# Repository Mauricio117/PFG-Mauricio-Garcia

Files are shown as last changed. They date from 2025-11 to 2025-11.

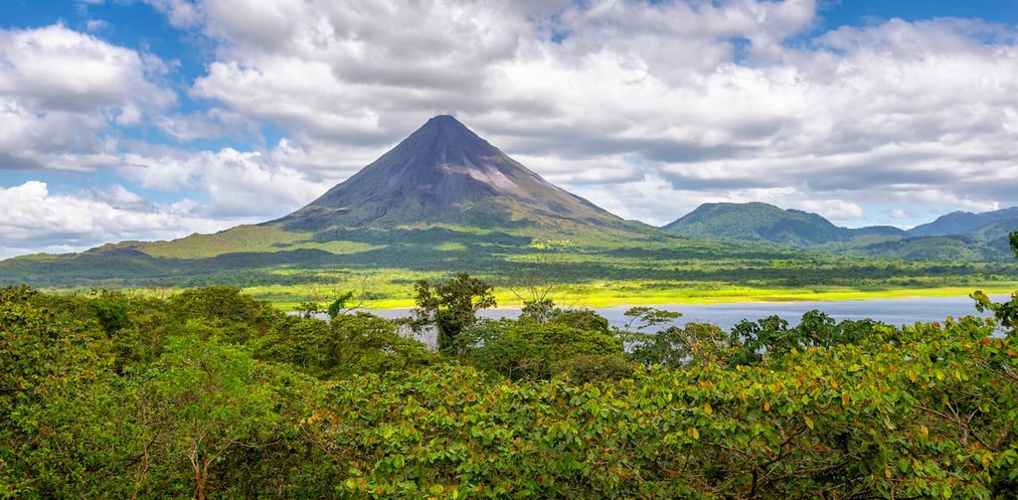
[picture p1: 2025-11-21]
Codigo TFG/imagenes/Costa_Rica.jpg

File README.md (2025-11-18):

# PFG-Mauricio-Garcia
Este repositorio contiene información del Proyecto Final de Graduación realizado en el LIMA del Tecnológico de Costa Rica. Se encuentran los archivos de programa de la interfaz gráfica: programación del Teensy e interfaz gráfica, y los modelos .stl de las piezas utilizadas en la implementación física.

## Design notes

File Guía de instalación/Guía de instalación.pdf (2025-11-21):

## Guía de instalación

## Dispositivo de rehabilitación de rodilla

En primer lugar, acceda al siguiente enlace:

https://www.python.org/downloads/

En la página, seleccione una versión de Python 3.10.x para la descarga.

En el desarrollo de este proyecto se utilizó Python 3.12.6, sin embargo, por

compatibilidad con las bibliotecas gráficas y de comunicación empleadas (Pygame,

Adafruit IO, pyserial y cryptography), se recomienda instalar la versión Python

3.10.14.

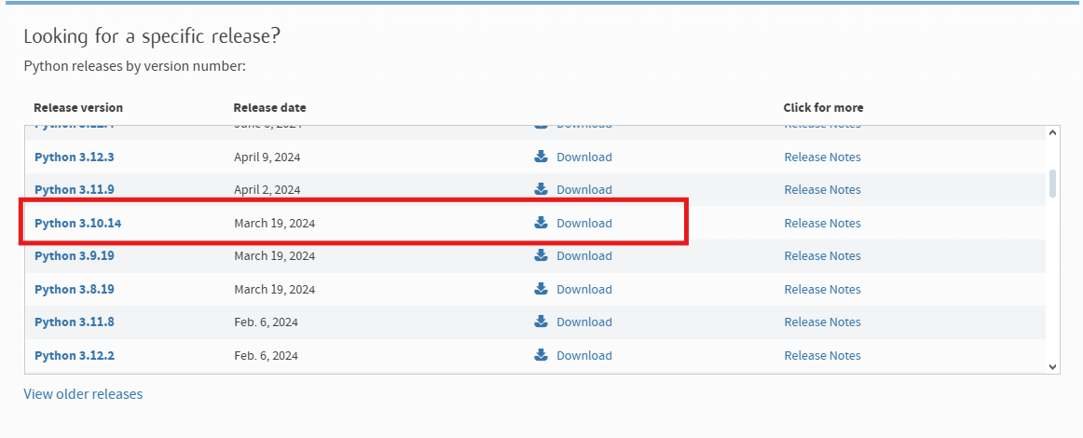
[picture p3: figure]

Una vez descargado, complete la instalación siguiendo los pasos del instalador,

asegurándose de marcar la opción “Add Python to PATH”.

Luego, abra el CMD de Windows y digite los siguientes comandos para instalar las

bibliotecas requeridas:

- pip install requests
- pip install pillow
- pip install adafruit-io
- pip install pygame
- pip install pyserial

Ahora debe instalar Arduino.

Para ello, vaya al enlace:

https://www.arduino.cc/en/software/

En la página, haga clic en la opción "Win 7 and newer". Una vez descargado, instale

el programa. Es importante que la versión de Arduino sea 1.8.X.

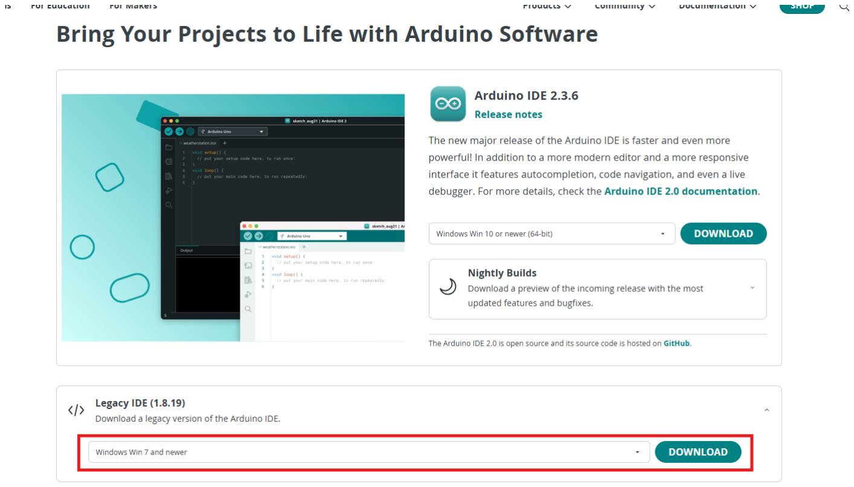
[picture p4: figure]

Luego, debe instalar Teensyduino para poder cargar el programa al Teensy 4.1.

Diríjase a:

https://www.pjrc.com/teensy/td_download.html

Descargue el instalador según el sistema operativo y siga los pasos que se

muestran.

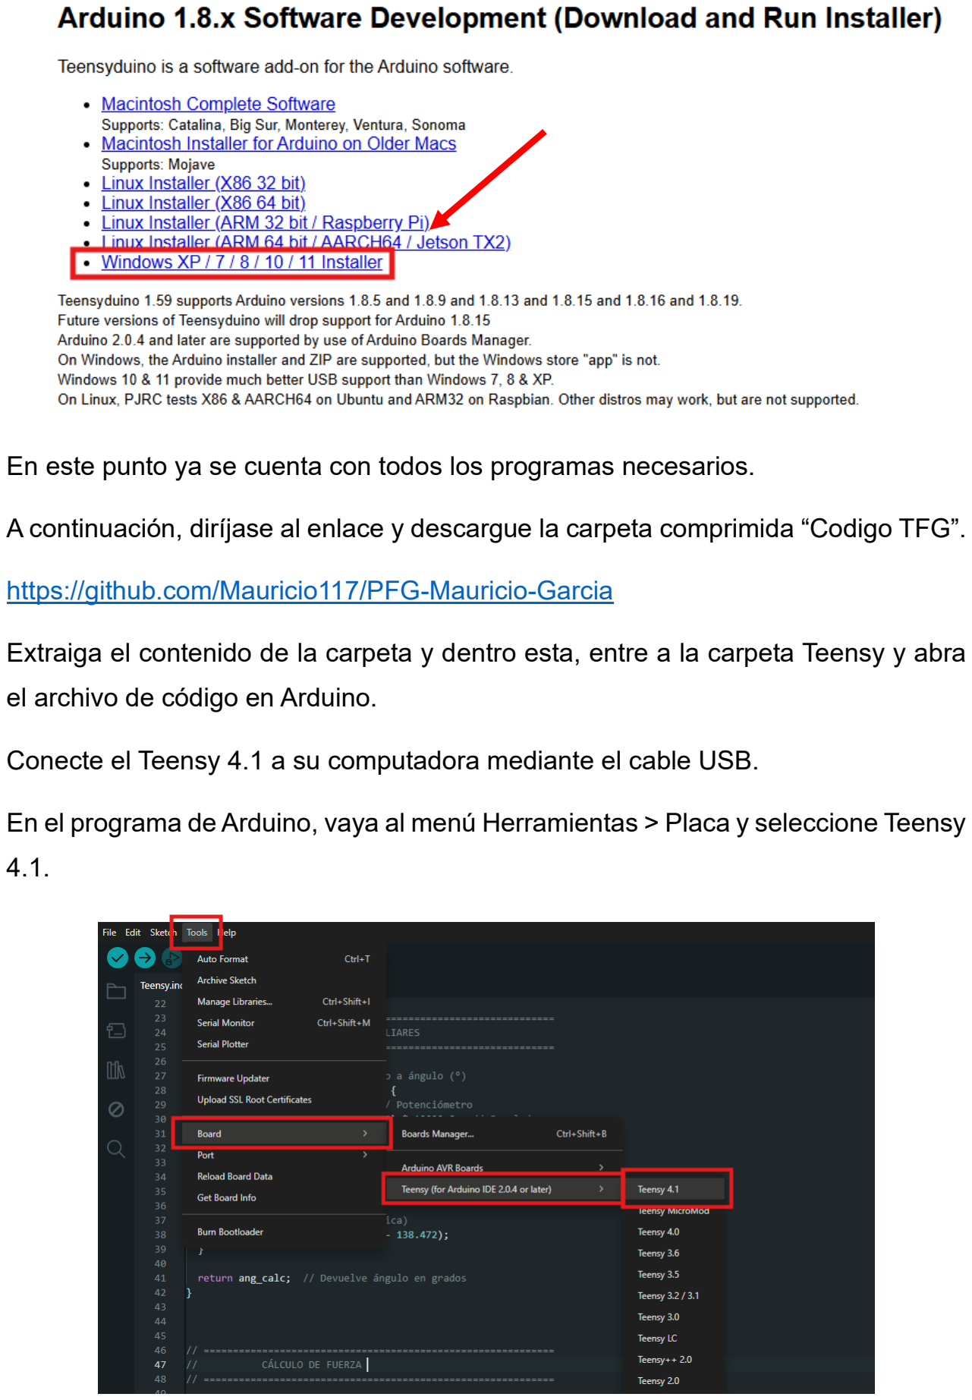
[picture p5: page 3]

En este punto ya se cuenta con todos los programas necesarios.

A continuación, diríjase al enlace y descargue la carpeta comprimida “Codigo TFG”.

https://github.com/Mauricio117/PFG-Mauricio-Garcia

Extraiga el contenido de la carpeta y dentro esta, entre a la carpeta Teensy y abra

el archivo de código en Arduino.

Conecte el Teensy 4.1 a su computadora mediante el cable USB.

En el programa de Arduino, vaya al menú Herramientas > Placa y seleccione Teensy

4.1.

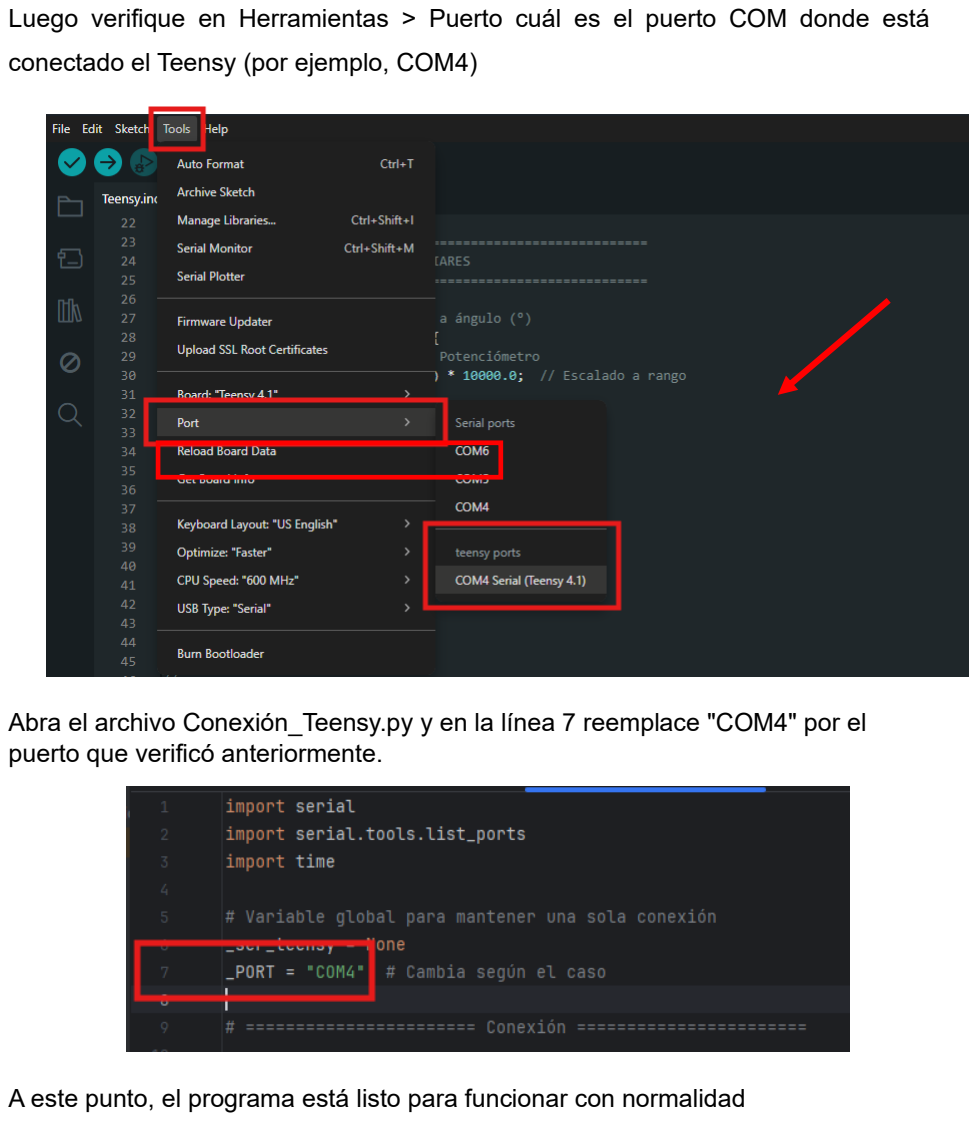
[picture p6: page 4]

Luego verifique en Herramientas > Puerto cuál es el puerto COM donde está

conectado el Teensy (por ejemplo, COM4)

Abra el archivo Conexión_Teensy.py y en la línea 7 reemplace "COM4" por el puerto que verificó anteriormente.

A este punto, el programa está listo para funcionar con normalidad

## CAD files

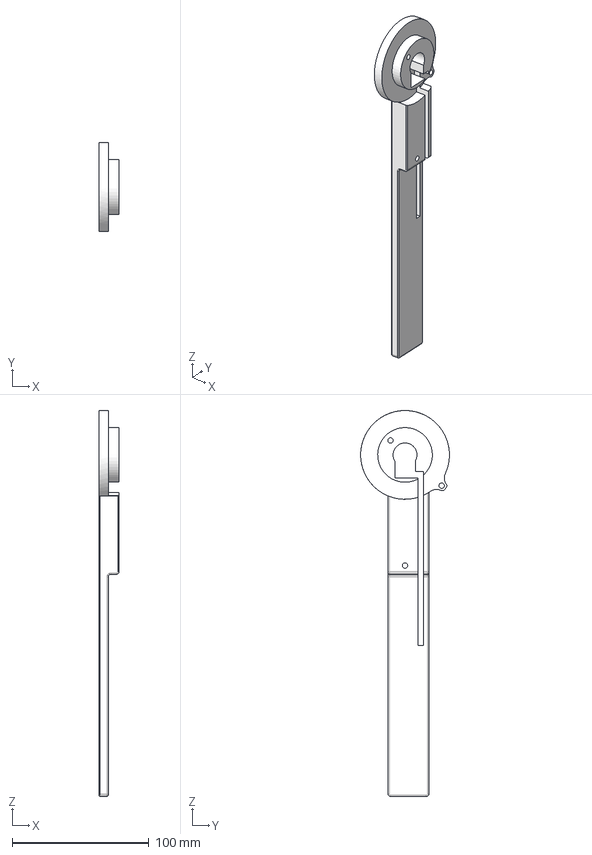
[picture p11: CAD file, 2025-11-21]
CAD/Pieza_horizontal.stp
15.0 x 64.9 x 282.5 mm

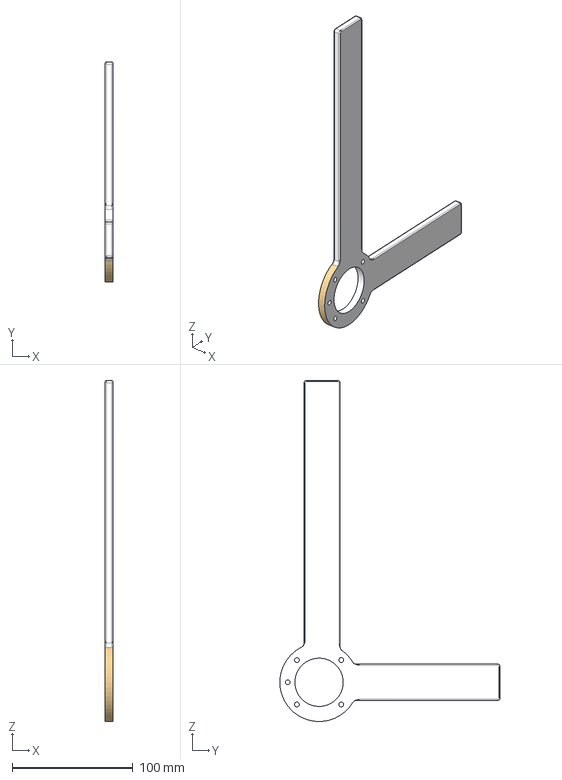
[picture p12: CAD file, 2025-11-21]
CAD/Pieza_vertical.stp
6.42 x 182.5 x 282.5 mm

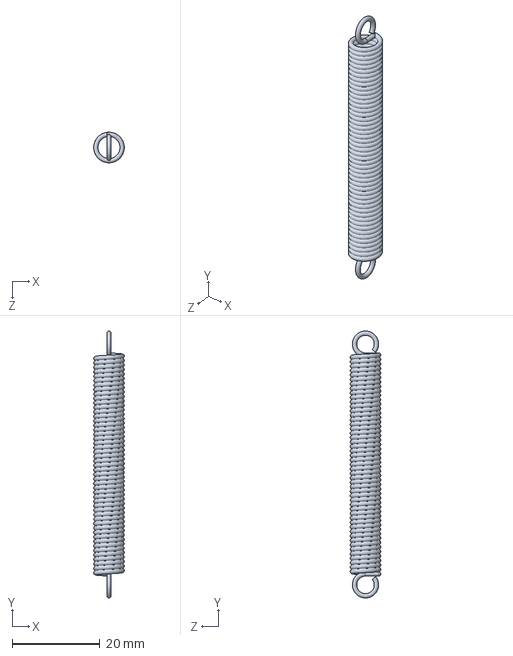
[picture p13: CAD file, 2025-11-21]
CAD/Resorte.SLDPRT
7.00 x 61.0 x 7.00 mm

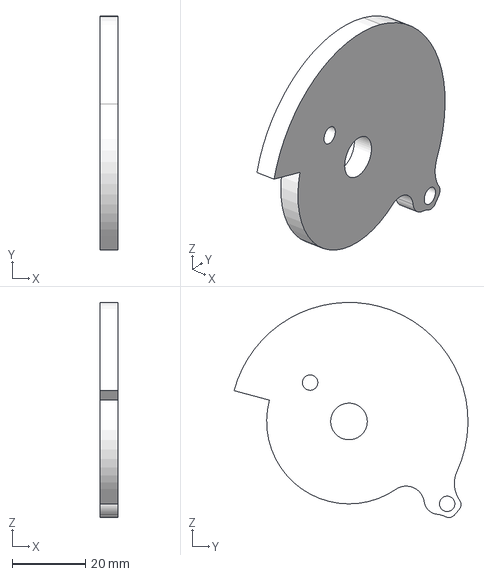
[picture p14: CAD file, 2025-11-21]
CAD/Tapa.stp
5.00 x 63.9 x 58.7 mm

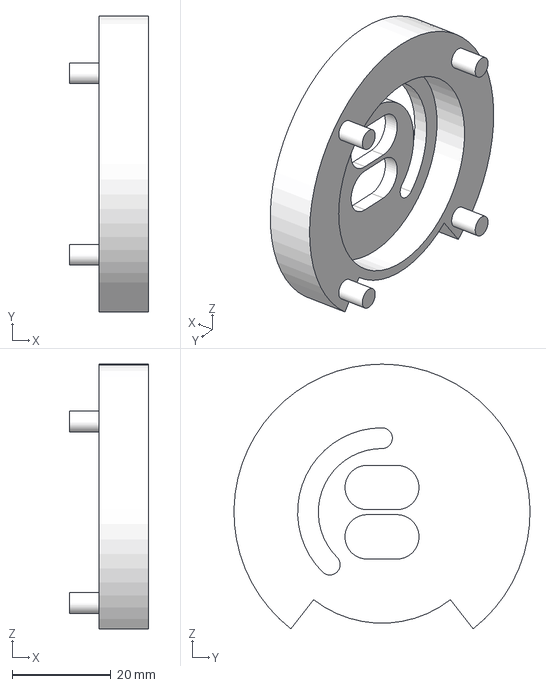
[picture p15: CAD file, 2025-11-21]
CAD/Sujecion potenciometro.stp
16.0 x 60.0 x 53.6 mm

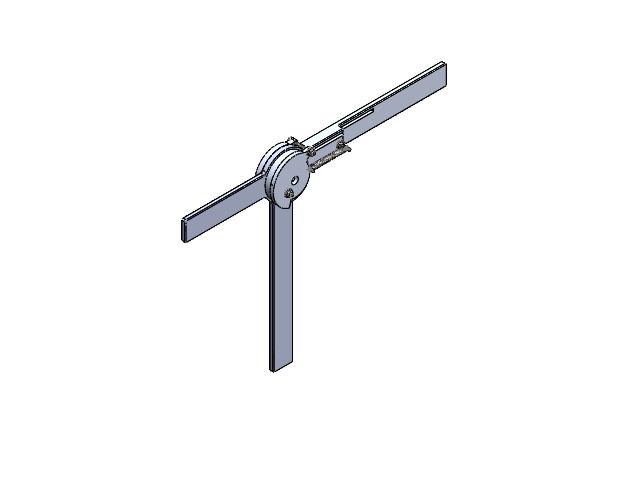
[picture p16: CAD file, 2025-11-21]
CAD/Ensamblaje.SLDASM
pan cross head_am x 4
Pieza_horizontal
Pieza_vertical
Sujecion potenciometro
Tapa
Resorte
flat washer regular_am x 4
hex nut style 1_am x 4

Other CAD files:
CAD/Pieza_horizontal.SLDPRT
CAD/Pieza_vertical.SLDPRT
CAD/Sujecion potenciometro.SLDPRT
CAD/Tapa.SLDPRT

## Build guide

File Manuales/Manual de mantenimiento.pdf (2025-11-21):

## Manual de mantenimiento

## Dispositivo de rehabilitación de rodilla

Mantenimiento preventivo:

El mantenimiento preventivo se realiza periódicamente con el fin de prolongar la

vida útil del dispositivo y reducir la probabilidad de fallos mecánicos, electrónicos o

de software.

Se recomienda efectuarlo cada mes o cada 30 sesiones de uso, lo que ocurra

primero.

Antes de iniciar cualquier procedimiento, asegúrese de:

- Desconectar el cable USB del dispositivo.

Inspección visual general

- Verifique que la estructura fija (zona del muslo) y la estructura móvil (zona

de la pantorrilla) no presenten grietas, deformaciones o desgaste.

- Asegúrese de que el punto de articulación esté firme y sin juego excesivo.
- Revise que la superficie donde el usuario apoya la pierna esté limpia y en

buen estado.

- Compruebe que el cableado que conecta el potenciómetro con el Teensy

4.1 esté intacto y no presente dobleces pronunciados.

Revisión mecánica

- Compruebe que el movimiento manual de la parte móvil sea suave y sin

fricción excesiva.

- Confirme que no existan piezas ni tornillos sueltos.

- Si se escucha sonido metálico o fricción, revise que la articulación esté

correctamente alineada.

Acceso a la parte electrónica

Retire los tornillos de la tapa que cubre la zona de conexión entre piezas

mecánicas.

Abra la tapa interna con cuidado, la cual está conectada con el potenciómetro.

Una vez abierta:

- Verifique el estado del cable USB y las conexiones internas.
- Compruebe que el Teensy 4.1 esté correctamente asentado en su base.
- Revise el cableado del potenciómetro, asegurándose de que los cables

estén bien sujetos y sin desgaste.

- Confirme que no existan signos de calentamiento o corrosión en los

conectores.

Limpieza interna

- Elimine el polvo con aire comprimido o un pincel suave.
- No aplique líquidos ni aerosoles dentro del compartimiento electrónico.

Vuelva a cerrar la tapa y coloque los tornillos.

Limpieza externa

- Limpie las superficies del dispositivo con un paño seco o ligeramente

húmedo.

- Evite productos abrasivos o solventes.
- Asegúrese de que la superficie de apoyo de la pierna esté limpia y libre de

partículas.

Verificación final

- Conecte nuevamente el dispositivo y abra la interfaz.
- Verifique que las lecturas del ángulo sean estables y coherentes.
- Mueva manualmente la estructura móvil y compruebe que el valor mostrado

en pantalla aumente y disminuya correctamente.

- Revise que el puerto COM sea detectado sin errores.
- Compruebe que el juego interactivo responda adecuadamente al

movimiento manual.

Mantenimiento correctivo:

Si el dispositivo presenta fallas durante su uso, utilice la tabla siguiente para

diagnosticar y resolver el problema.

Tabla 1. Fallos comunes y acciones recomendadas

Síntoma o falla detectada | Posible causa | Acción recomendada
El dispositivo no es detectado por la computadora | • Cable USB dañado • Puerto COM inhabilitado | • Cambiar cable USB • Probar otro puerto
La interfaz no muestra lecturas de ángulo | • Potenciómetro desconectado • Cable roto o flojo • Teensy no reconocido | • Revisar conexión del potenciómetro • Verificar continuidad de cables • Reconectar el Teensy
La lectura del ángulo es inestable | • Potenciómetro desgastado • Ruido eléctrico en el cable | • Ajustar conexión • Reemplazar potenciómetro si aplica
El juego no responde al movimiento | • Lectura del potenciómetro errónea • Puerto COM incorrecto | • Revisar cableado • Seleccionar el puerto COM correcto
La interfaz gráfica no inicia | • Librerías no instaladas • Error en el código Python | • Reinstalar librerías requeridas

| | • Revisar mensajes en consola
Datos de usuario no se guardan | • Error de escritura del archivo cifrado • Adafruit IO sin conexión | • Verificar carpeta “Datos Locales” • Revisar conexión a Internet
Ruido en la articulación | • Piezas mal alineadas | • Realinear las piezas
El movimiento manual está rígido | • Acumulación de polvo • Fricción en el punto de giro | • Limpiar superficie de contacto • Revisar y reajustar articulación

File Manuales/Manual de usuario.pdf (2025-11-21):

## Manual de usuario

## Dispositivo de rehabilitación de rodilla

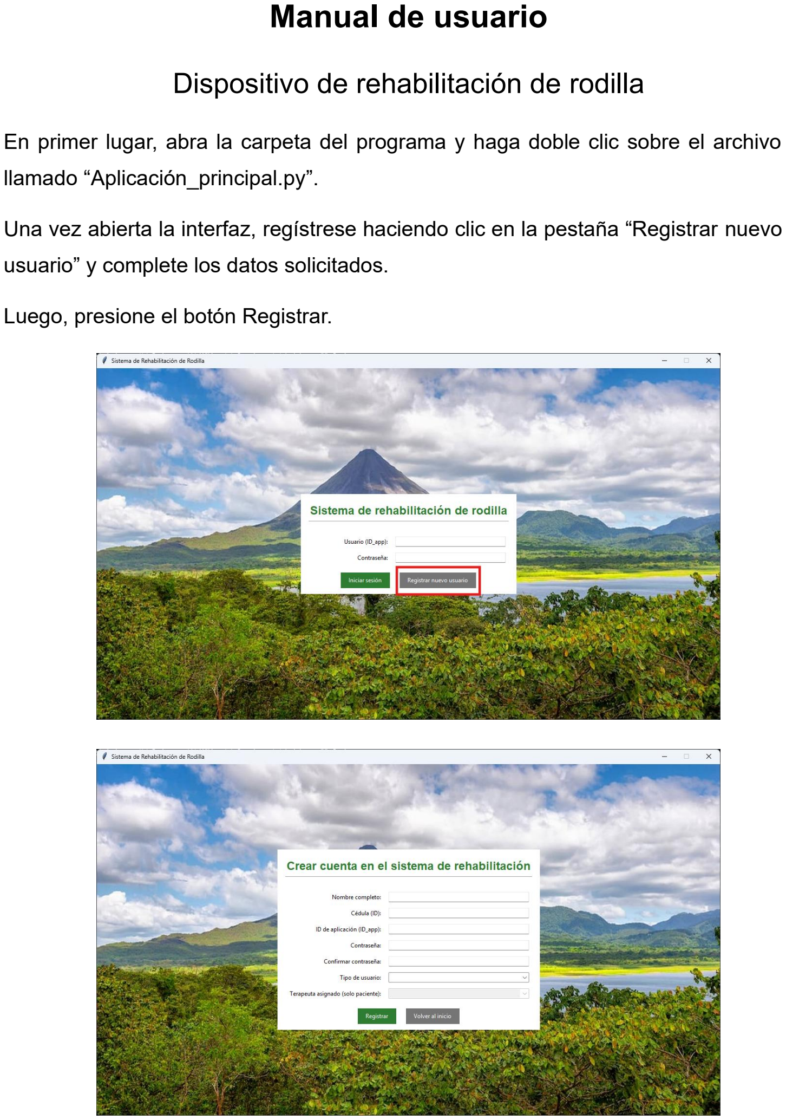
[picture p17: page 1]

En primer lugar, abra la carpeta del programa y haga doble clic sobre el archivo

llamado “Aplicación_principal.py”.

Una vez abierta la interfaz, regístrese haciendo clic en la pestaña “Registrar nuevo

usuario” y complete los datos solicitados.

Luego, presione el botón Registrar.

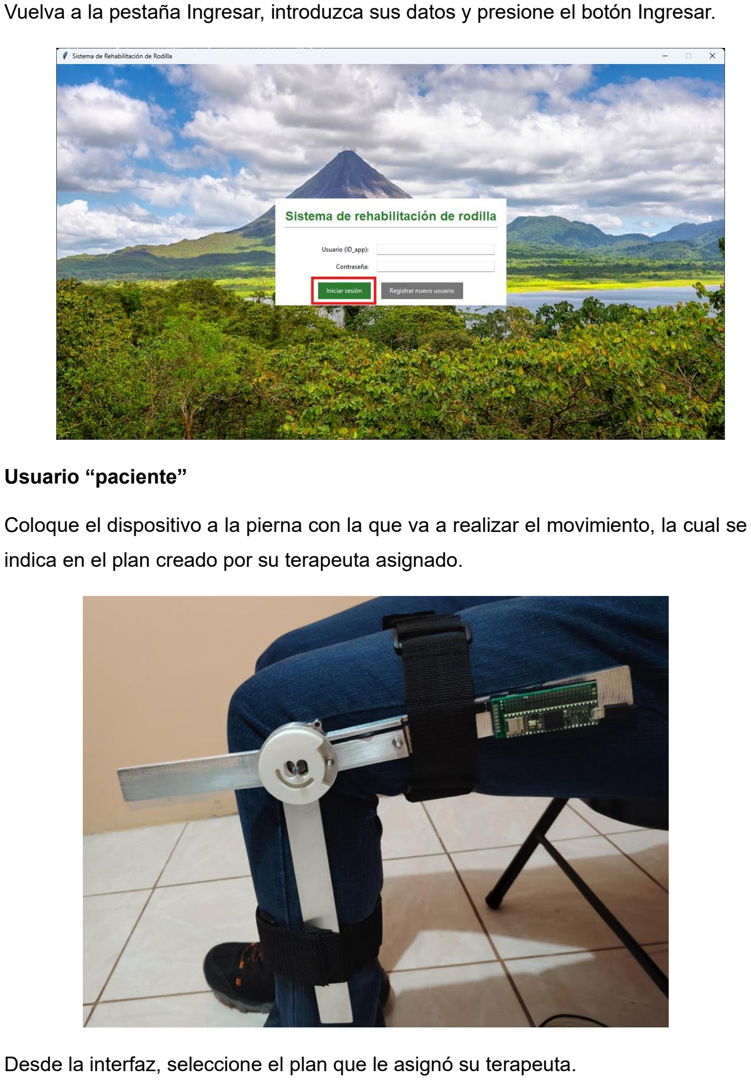
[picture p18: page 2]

Vuelva a la pestaña Ingresar, introduzca sus datos y presione el botón Ingresar.

Usuario “paciente”

Coloque el dispositivo a la pierna con la que va a realizar el movimiento, la cual se

indica en el plan creado por su terapeuta asignado.

Desde la interfaz, seleccione el plan que le asignó su terapeuta.

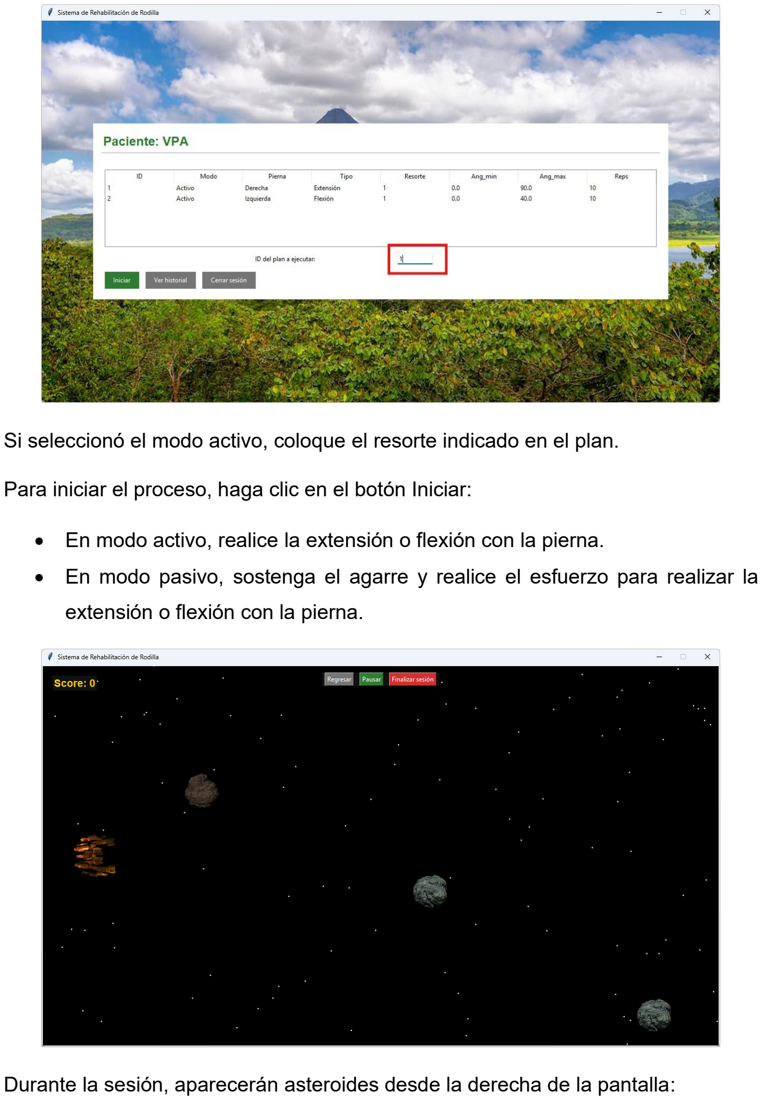
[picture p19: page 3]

Si seleccionó el modo activo, coloque el resorte indicado en el plan.

Para iniciar el proceso, haga clic en el botón Iniciar:

- En modo activo, realice la extensión o flexión con la pierna.
- En modo pasivo, sostenga el agarre y realice el esfuerzo para realizar la

extensión o flexión con la pierna.

Durante la sesión, aparecerán asteroides desde la derecha de la pantalla:

Debe intentar destruirlos moviendo la pierna.

- Si se mueve la pierna hacia arriba, la nave se desplaza hacia arriba.
- Si se mueve la pierna hacia abajo, la nave se desplaza hacia abajo.

La sesión termina al completar las repeticiones indicadas en el plan.

Usuario “terapeuta”

Si inicia sesión con un usuario de tipo “terapeuta”, aparecerá una pantalla con los

datos de las sesiones de los usuarios.

Seleccione un usuario desde la pestaña de paciente. Los panes del paciente se

mostrarán automáticamente. Además, puede crear nuevos planes para dicho

usuario. El botón “Subir a Adafruit IO” permite sincronizar los datos del paciente con

la nube cuando se presenta una conexión activa a internet.

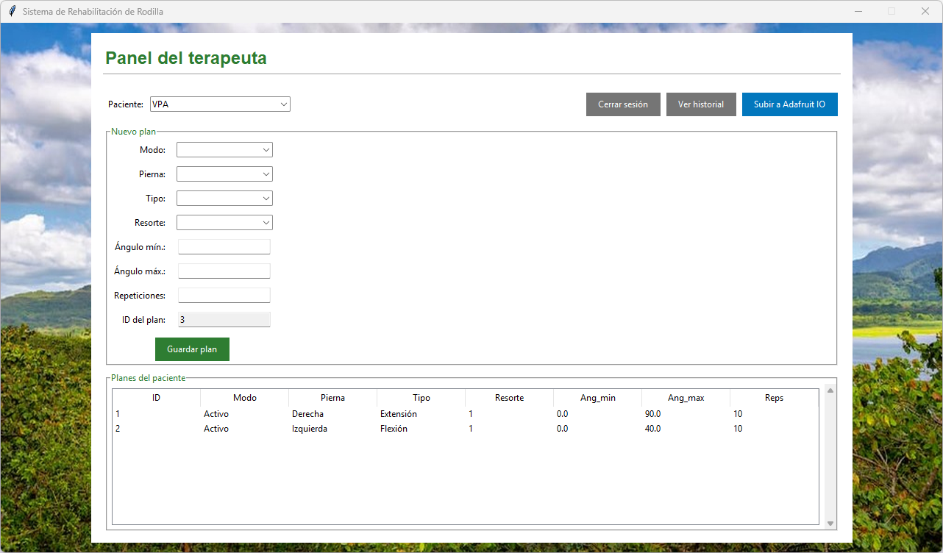
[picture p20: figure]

Para ver el resumen de las sesiones del usuario presione el botón “Ver historial”.

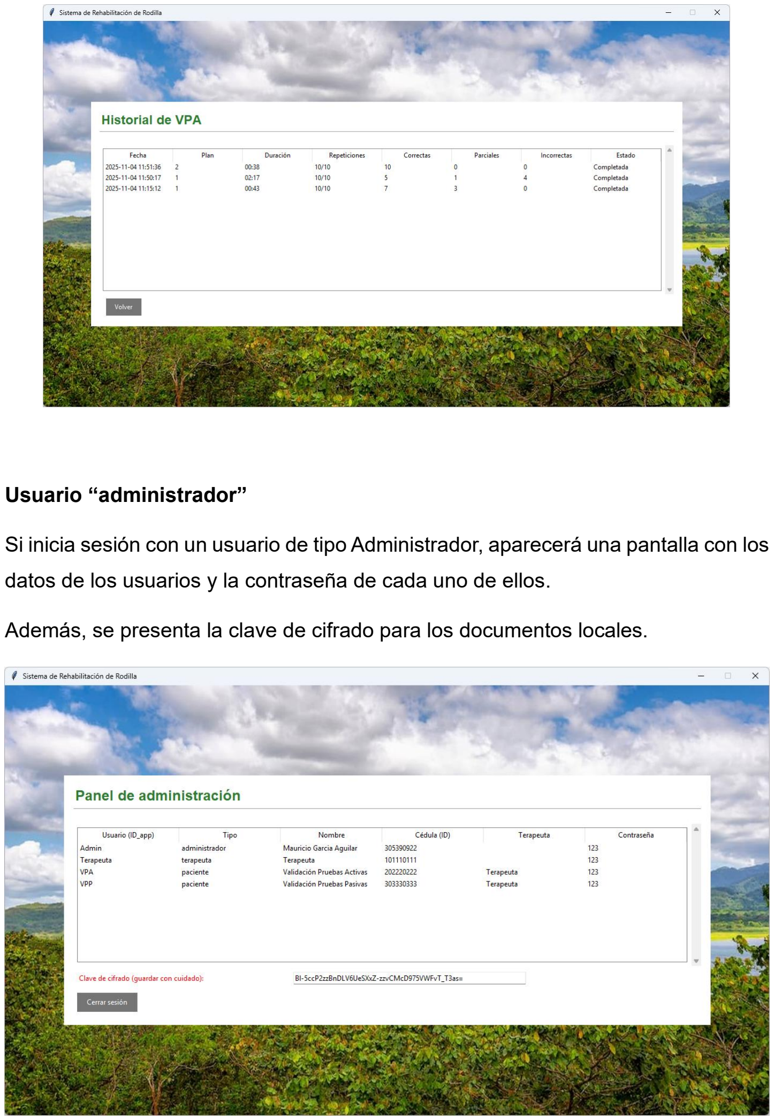
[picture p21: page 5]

Usuario “administrador”

Si inicia sesión con un usuario de tipo Administrador, aparecerá una pantalla con los

datos de los usuarios y la contraseña de cada uno de ellos.

Además, se presenta la clave de cifrado para los documentos locales.

Recomendaciones generales

- No utilice el dispositivo si observa ruidos anormales, lecturas inestables,

holguras en tornillos o desgaste en las piezas.

- Manténgalo en un lugar seco, limpio y protegido, evitando exposición a

humedad, polvo excesivo o temperaturas extremas.

- Utilice el equipo únicamente sobre una superficie firme, estable y nivelada

para asegurar un movimiento adecuado de la articulación.

- Evite manipular cables, piezas internas, el Teensy 4.1 o el software del

sistema sin conocimientos técnicos o sin seguir el manual correspondiente.

- Realice copias de respaldo de los datos almacenados en la aplicación,

especialmente si varios usuarios o terapeutas utilizan el sistema.

- No coloque las manos sobre el mecanismo de movimiento o el eje mientras

el dispositivo se encuentre en funcionamiento.

- Asegúrese de que las sujeciones de la pierna esten correctamente ajustada

antes de iniciar el modo activo o pasivo para evitar deslizamientos.

- Verifique antes de cada sesión que el cable USB y el Teensy estén

correctamente conectados al puerto COM correspondiente.

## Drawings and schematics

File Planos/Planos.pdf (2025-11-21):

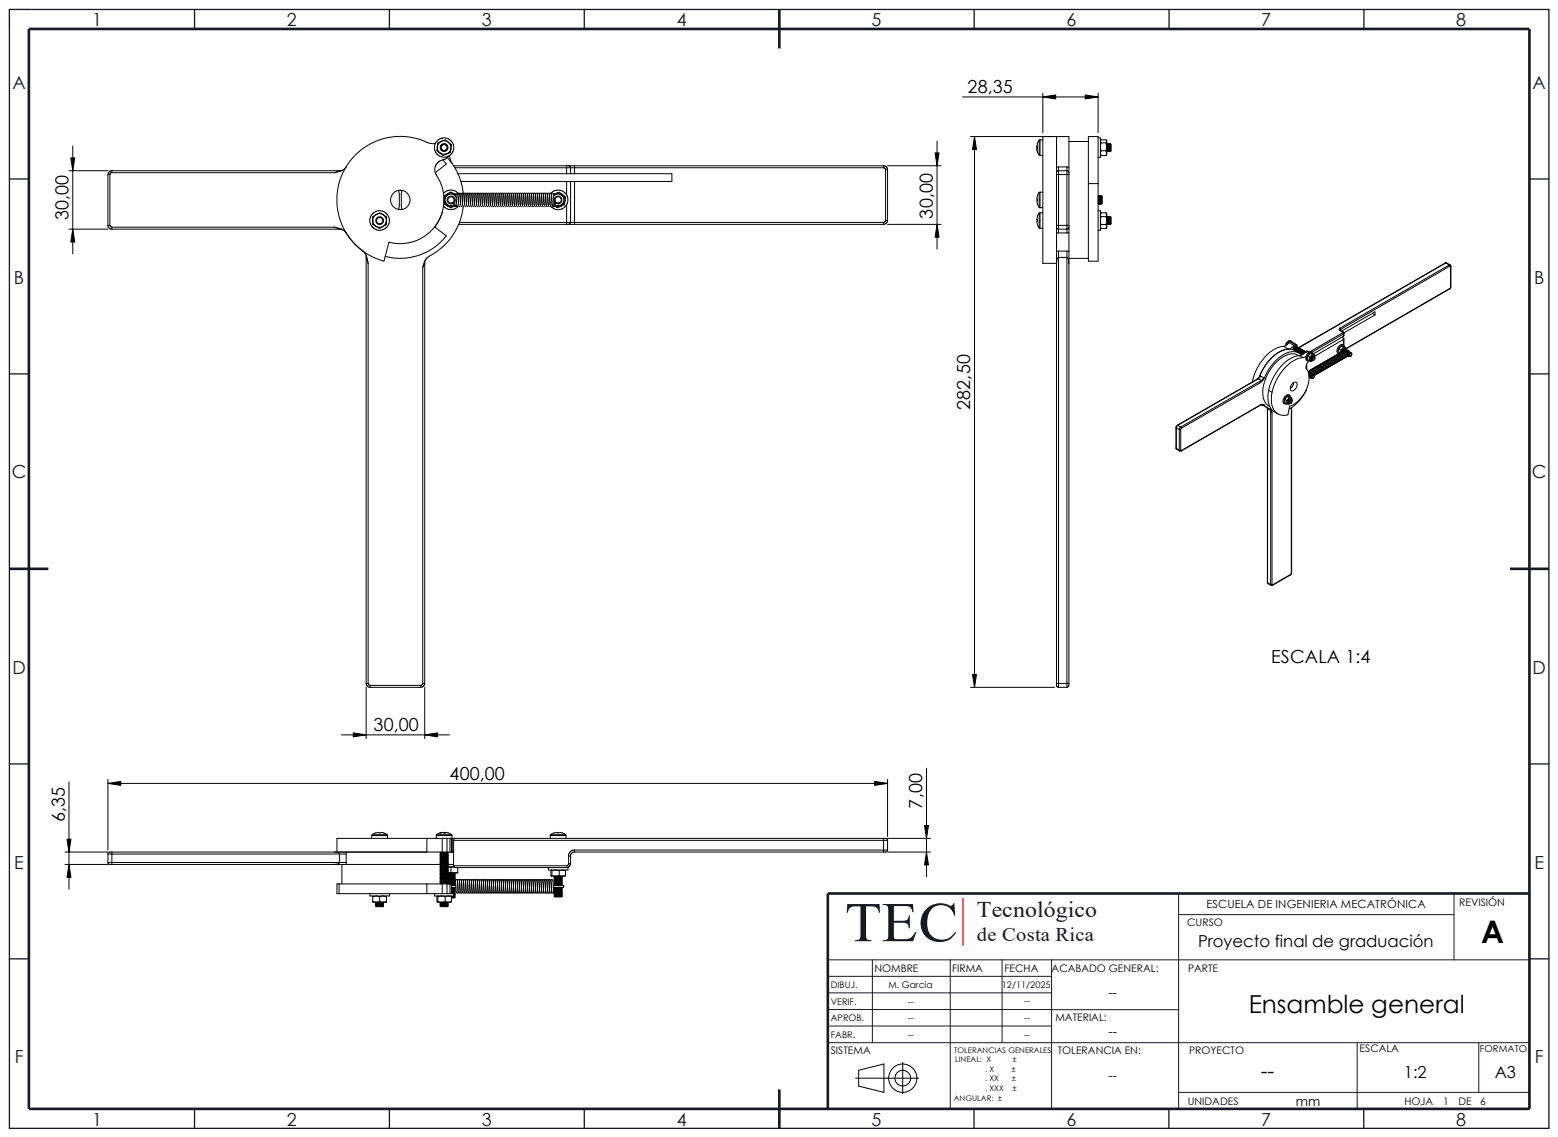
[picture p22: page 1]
Tecnológico TEC; CURSO; REVISIÓN; ESCALA 1:4

ESCUELA DE INGENIERIA MECATRÓNICA
Proyecto final de graduación

de Costa Rica

NOMBRE | FIRMA | FECHA | ACABADO GENERAL: -- | PARTE Ensamble general
DIBUJ. | M. García | | 12/11/2025
VERIF. | -- | | --

APROB. | -- | | -- | MATERIAL: --
FABR. | -- | | --
SISTEMA | | | TOLERANCIAS GENERALES LINEAL: X ± . XX ± . X ± . XXX ± ANGULAR: ± | TOLERANCIA EN: -- | PROYECTO -- | ESCALA 1:2 | FORMATO A3

mm UNIDADES | HOJA 1 6 DE

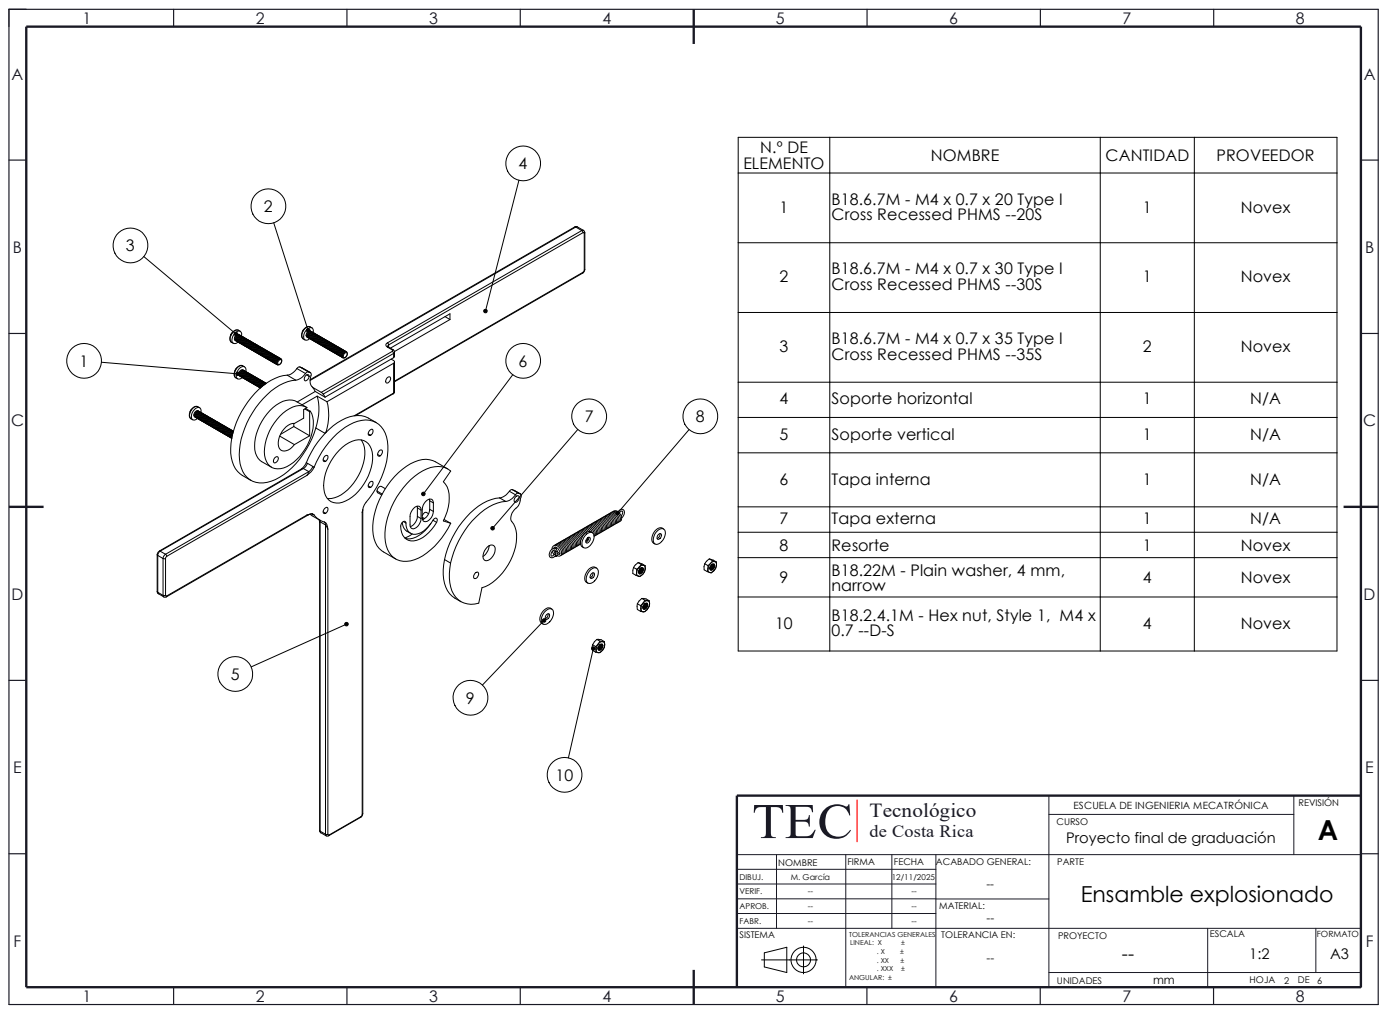
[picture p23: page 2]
Tecnológico TEC; CURSO; REVISIÓN

N.º DE ELEMENTO | NOMBRE | CANTIDAD | PROVEEDOR

1 | B18.6.7M - M4 x 0.7 x 20 Type I Cross Recessed PHMS --20S | 1 | Novex

2 | B18.6.7M - M4 x 0.7 x 30 Type I Cross Recessed PHMS --30S | 1 | Novex

3 | B18.6.7M - M4 x 0.7 x 35 Type I Cross Recessed PHMS --35S | 2 | Novex

4 | Soporte horizontal | 1 | N/A
5 | Soporte vertical | 1 | N/A

6 | Tapa interna | 1 | N/A

7 | Tapa externa | 1 | N/A
8 | Resorte | 1 | Novex
9 | B18.22M - Plain washer, 4 mm, narrow | 4 | Novex

10 B18.2.4.1M - Hex nut, Style 1, M4 x | 0.7 --D-S | 4 | Novex

ESCUELA DE INGENIERIA MECATRÓNICA
Proyecto final de graduación

de Costa Rica

NOMBRE | FIRMA | FECHA | ACABADO GENERAL: -- | PARTE Ensamble explosionado

DIBUJ. | M. García | | 12/11/2025
VERIF. | -- | | --
APROB. | -- | | -- | MATERIAL:
FABR. | | | -- | -- --

LINEAL: X ± . XX ± . X ± . XXX ± ANGULAR: ± | | PROYECTO -- | ESCALA 1:2 | FORMATO

15,00 32,50

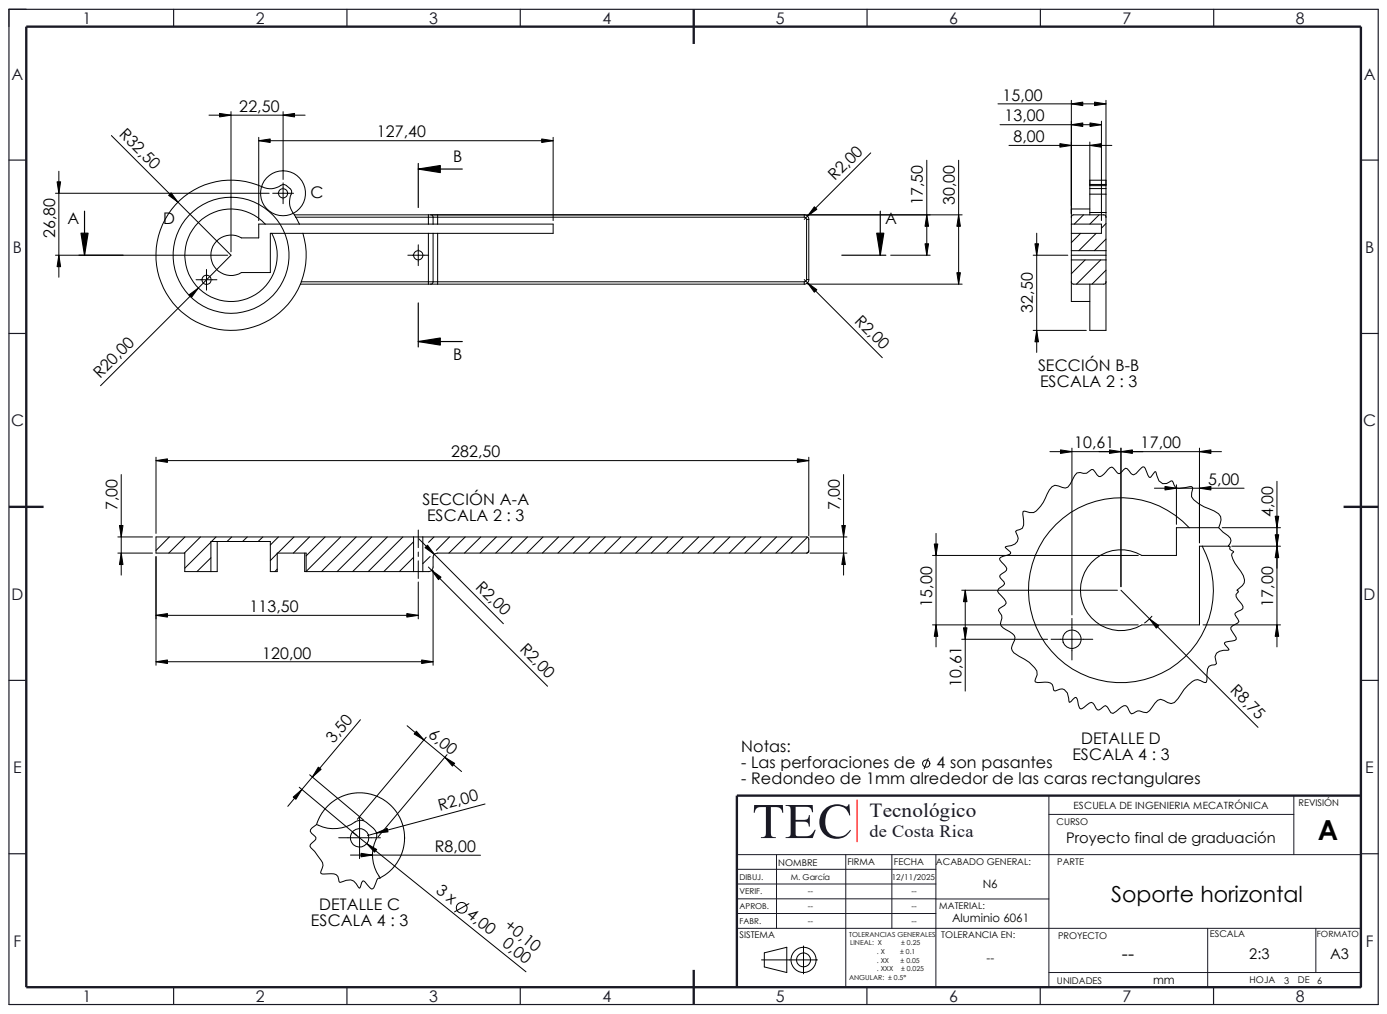
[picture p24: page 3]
SECCIÓN B-B ESCALA 2 : 3; SECCIÓN A-A; ESCALA 2 : 3 ⁷,00; DETALLE C ESCALA 4 : 3; DETALLE D ESCALA 4 : 3; CURSO; REVISIÓN

Notas:
- Las perforaciones de 4 son pasantes
- Redondeo de 1mm alrededor de las caras rectangulares
Tecnológico TEC

ESCUELA DE INGENIERIA MECATRÓNICA
Proyecto final de graduación

de Costa Rica

NOMBRE | FIRMA | FECHA | ACABADO GENERAL: N6 | PARTE Soporte horizontal

DIBUJ. | M. García | | 12/11/2025
VERIF. | -- | | --
APROB. | -- | | -- | MATERIAL: Aluminio 6061
FABR. | -- | | --

LINEAL: X ± 0.25 . XX ± 0.05 . X ± 0.1 . XXX ± 0.025 ANGULAR: ± 0.5° | | PROYECTO -- | ESCALA 2:3 | FORMATO

6,35 8,00

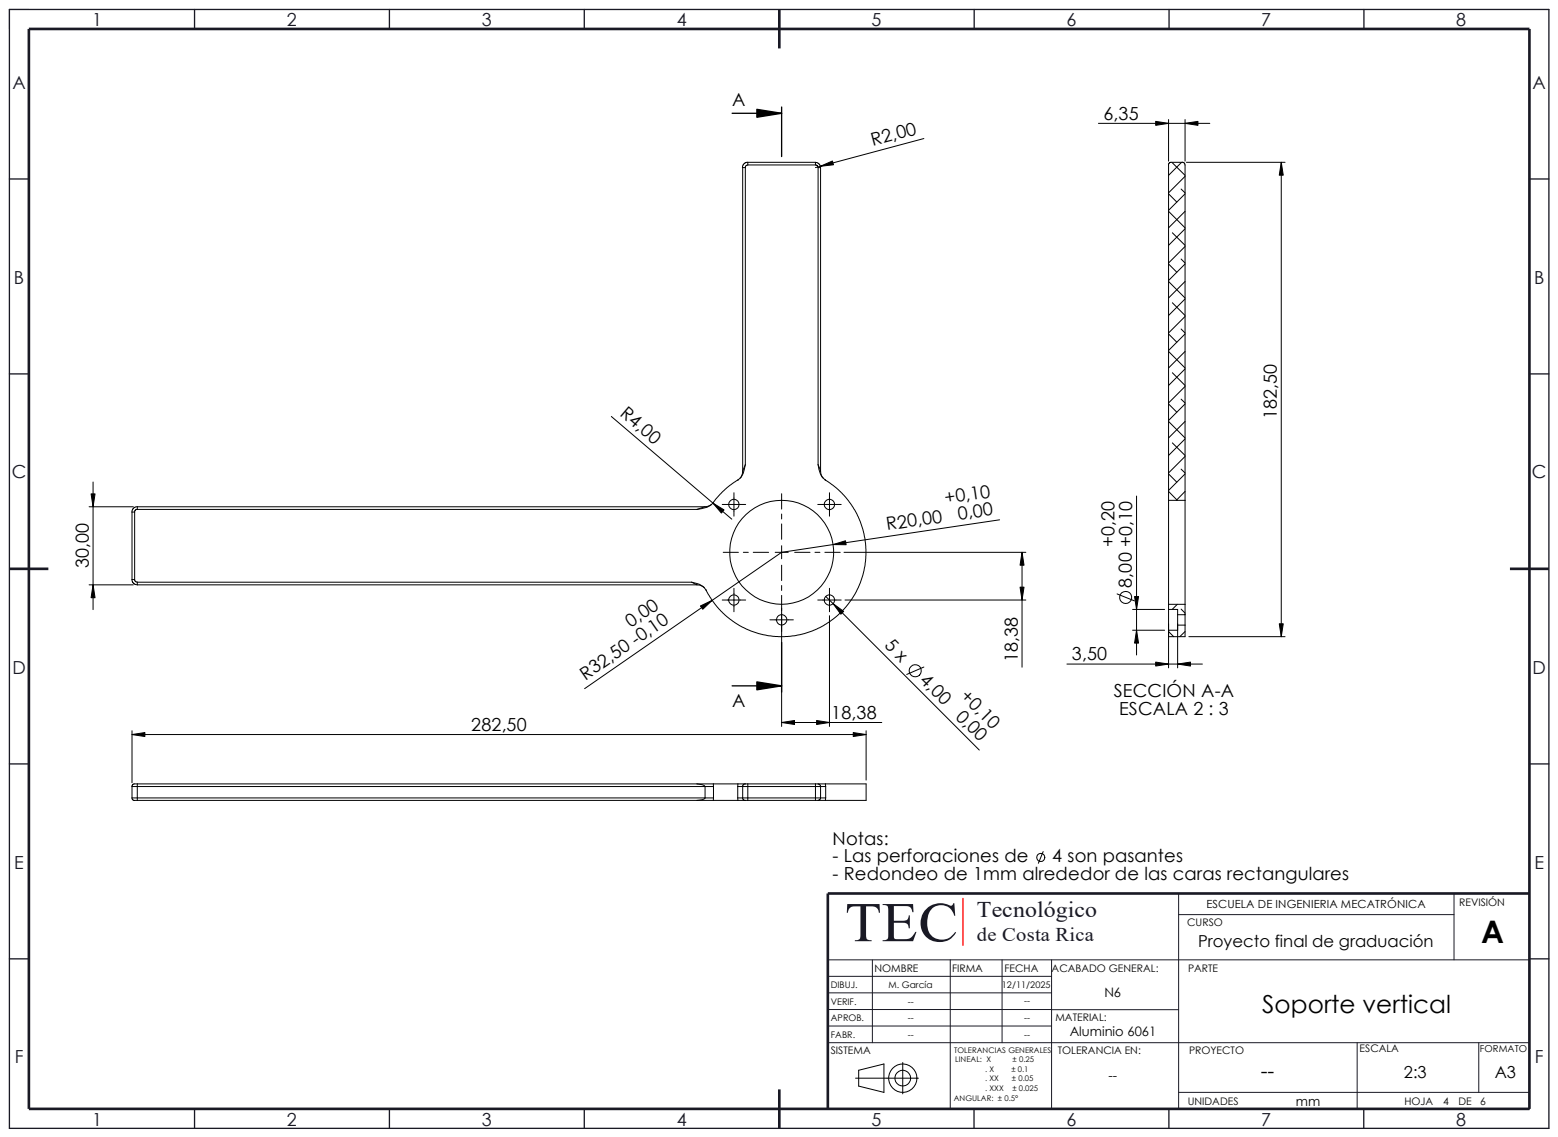
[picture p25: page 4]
SECCIÓN A-A ESCALA 2 : 3; CURSO; REVISIÓN

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

ESCUELA DE INGENIERIA MECATRÓNICA
Proyecto final de graduación

de Costa Rica

NOMBRE | FIRMA | FECHA | ACABADO GENERAL: N6 | PARTE Soporte vertical

DIBUJ. | M. García | | 12/11/2025
VERIF. | -- | | --
APROB. | -- | | -- | MATERIAL: Aluminio 6061
FABR. | -- | | --

. XX ± 0.05 | | PROYECTO -- | ESCALA 2:3 | FORMATO

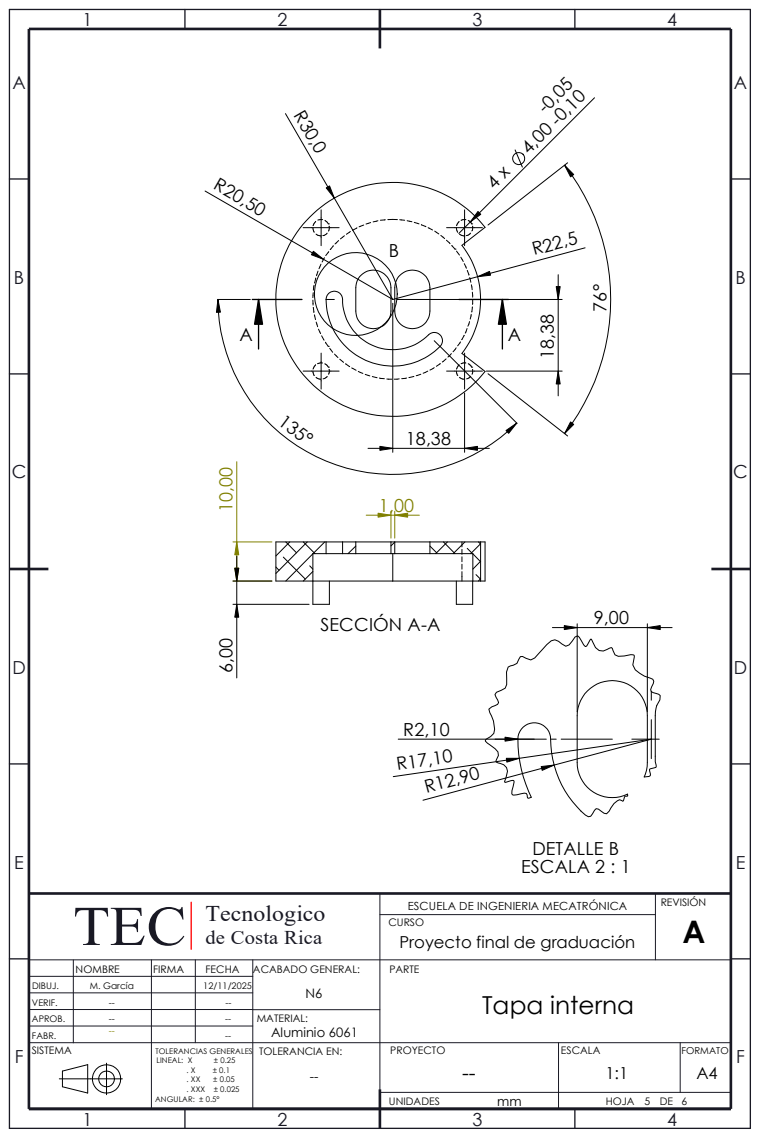
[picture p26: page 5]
SECCIÓN A-A ¹⁰,00; DETALLE B ESCALA 2 : 1; TEC; de Costa Rica; Tecnologico; CURSO; REVISIÓN

ESCUELA DE INGENIERIA MECATRÓNICA
Proyecto final de graduación

NOMBRE | FIRMA | FECHA | ACABADO GENERAL: | PARTE Tapa interna N6

DIBUJ. | M. García | | 12/11/2025
VERIF. | -- | | --
APROB. | -- | | -- | MATERIAL: Aluminio 6061
FABR. | -- | | --

TOLERANCIAS GENERALES . XX ± 0.05 | -- | PROYECTO | ESCALA 1:1 | FORMATO A4

UNIDADES mm | HOJA DE 5 6

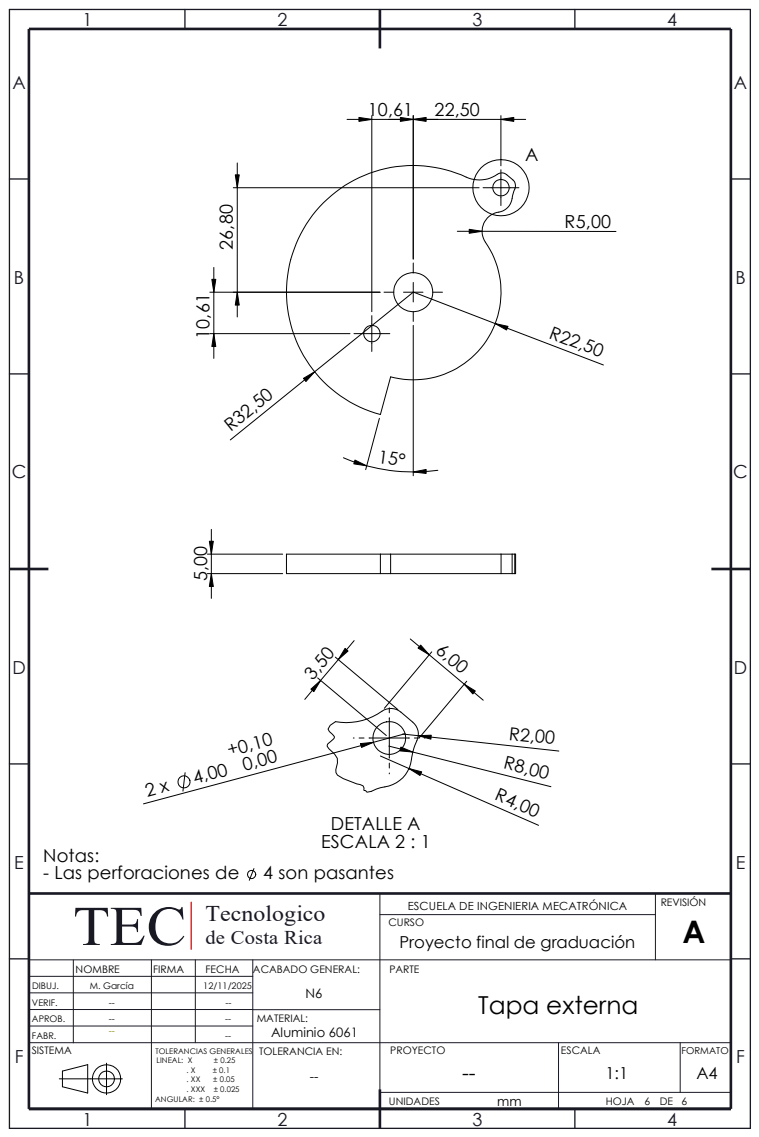
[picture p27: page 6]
DETALLE A ESCALA 2 : 1; TEC; de Costa Rica; Tecnologico; CURSO; REVISIÓN

Notas:
- Las perforaciones de 4 son pasantes

ESCUELA DE INGENIERIA MECATRÓNICA
Proyecto final de graduación

NOMBRE | FIRMA | FECHA | ACABADO GENERAL: | PARTE Tapa externa N6

DIBUJ. | M. García | | 12/11/2025
VERIF. | -- | | --
APROB. | -- | | -- | MATERIAL: Aluminio 6061
FABR. | -- | | --

TOLERANCIAS GENERALES . XX ± 0.05 | -- | PROYECTO -- | ESCALA 1:1 | FORMATO A4

UNIDADES mm | HOJA DE 6 6

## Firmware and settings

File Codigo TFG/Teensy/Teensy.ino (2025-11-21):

// ------------------- CONFIGURACIÓN -------------------
struct Resorte {
  float L0;          // Longitud efectiva inicial (m)
  float constante;   // Constante K (N/m)
};

// Datos de los resortes: {L0, K}
Resorte resortes[3] = {
  {0.045, 428.3},  // Resorte 1 
  {0.046, 595.6},  // Resorte 2 
  {0.04, 12146.8}   // Resorte 3 
};


// ------------------- VARIABLES -------------------
int resorte_sel = 0;   // 0 = sin resorte
char modo_sel = 'E';   // 'E' = Extensión, 'F' = Flexión

float angulo = 0.0;
float fuerza = 0.0;


// ============================================================
//                  FUNCIONES AUXILIARES
// ============================================================

// Leer potenciómetro y convertirlo a ángulo (°)
float leerPotenciometro(char modo) {
  int lectura = analogRead(A10); // Potenciómetro
  float pot_val = (lectura / 1023.0) * 10000.0;  // Escalado a rango
  float ang_calc = 0;

  if (modo == 'E') {
    // Ecuación de extensión (ajustar tras calibración)
    ang_calc = (0.0274 * pot_val - 138.472);
  } else {
    // Ecuación de flexión (simétrica)
    ang_calc = -(0.0274 * pot_val - 138.472);
  }

  return ang_calc;  // Devuelve ángulo en grados
}



// ============================================================
//           CÁLCULO DE FUERZA SEGÚN GEOMETRÍA REAL
// ============================================================

float calcularFuerza(float angulo, int sel, char modo) {
  if (sel == 0)
    return 0; // Sin resorte seleccionado

  // ---------- PARÁMETROS GEOMÉTRICOS ----------
  const float a = 0.081;  // Distancia punto fijo (m)
  const float r = 0.026;  // Radio brazo móvil (m)
  const float L0_geom = fabs(a - r); // Longitud inicial (posición 0°)

  // ---------- SELECCIÓN DE RESORTE ----------
  Resorte res = resortes[sel - 1];

  // Conversión a radianes
  float theta = angulo * PI / 180.0;

  // ---------- CÁLCULO DE LONGITUD Y DEFORMACIÓN ----------
  float L = sqrt(pow(r * cos(theta) - a, 2) + pow(r * sin(theta), 2));  // Longitud actual
  float deltaL = L - L0_geom;   // Deformación (m)

  if (deltaL < 0)
    deltaL = 0;  // El resorte no empuja si está comprimido

  // ---------- FUERZA DEL RESORTE ----------
  float F = res.constante * deltaL;  // N

  return F;  // Devuelve fuerza en Newtons
}



// ============================================================
//                     SETUP Y LOOP
// ============================================================

void setup() {
  Serial.begin(115200);
  delay(500);
  Serial.println("Teensy listo. Esperando comandos...");
}



void loop() {
  // ---------- LECTURA DE COMANDOS DESDE PC ----------
  if (Serial.available()) {
    char c = Serial.read();

    // Seleccionar resorte (0–3)
    if (c >= '0' && c <= '3') {
      resorte_sel = c - '0';
      Serial.print("Resorte seleccionado: ");
      Serial.println(resorte_sel);
    }

    // Seleccionar modo ('E' o 'F')
    else if (c == 'E' || c == 'F') {
      modo_sel = c;
      Serial.print("Modo: ");
      Serial.println(modo_sel == 'E' ? "Extensión" : "Flexión");
    }
  }

  // ---------- LECTURA DE ÁNGULO ----------
  angulo = leerPotenciometro(modo_sel);

  // ---------- CÁLCULO DE FUERZA ----------
  fuerza = calcularFuerza(angulo, resorte_sel, modo_sel);

  // ---------- ENVÍO DE DATOS ----------
  Serial.print(angulo, 2);
  Serial.print(",");
  Serial.println(fuerza, 3);

  delay(100);  // Frecuencia ~10 Hz
}

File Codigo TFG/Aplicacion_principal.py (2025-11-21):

import threading
import os
import tkinter as tk
from tkinter import ttk, messagebox
from PIL import Image, ImageTk
import json
from datetime import datetime
from Encriptacion import load_or_create_key, ensure_dirs, read_encrypted
from Usuarios import (    add_user, verify_login, get_user, list_users,
    upsert_planes, list_session_summaries, list_therapists, list_patients)
from Conexion_Adafruit import threaded_upload_user, sync_users_with_cloud, send_data_http
from Juego import KneeRehabilitationGame


# ==========================================================
# Utilidades gráficas
# ==========================================================

def set_background(root, image_path="imagenes/Costa_Rica.jpg"):
    """Fondo escalado al tamaño de la ventana, sin tapar la barra de estado."""
    for w in root.winfo_children():
        if isinstance(w, tk.Canvas) and getattr(w, "_is_bg", False):
            w.destroy()
    try:
        img = Image.open(image_path).resize((1280, 720), Image.LANCZOS)
        tkimg = ImageTk.PhotoImage(img)
        canvas = tk.Canvas(root, width=1280, height=720, highlightthickness=0, bd=0)
        canvas._is_bg = True
        canvas.place(x=0, y=0, relwidth=1, relheight=1)
        canvas.background = tkimg
        canvas.create_image(0, 0, image=tkimg, anchor="nw")

        root.after_idle(lambda: canvas.lower("all"))

    except Exception as e:
        print("[Background] Error:", e)
        root.configure(bg="#f5f5f5")


    except Exception as e:
        print("[Background] Error:", e)
        root.configure(bg="#f5f5f5")



def make_card(root, title_text):
    """Tarjeta central blanca con título y separador."""
    card = tk.Frame(root, bg="#ffffff", bd=0, highlightthickness=0)
    card.place(relx=0.5, rely=0.5, anchor="center")
    card.configure(highlightbackground="#e0e0e0", highlightcolor="#e0e0e0")

    title = tk.Label(card, text=title_text, font=("Arial", 18, "bold"), fg="#2e7d32", bg="#ffffff")
    title.grid(row=0, column=0, sticky="w", padx=16, pady=(16, 4))

    sep = ttk.Separator(card, orient="horizontal")
    sep.grid(row=1, column=0, sticky="ew", padx=16, pady=(0, 12))

    inner = tk.Frame(card, bg="#ffffff")
    inner.grid(row=2, column=0, sticky="nsew", padx=16, pady=12)

    card.grid_columnconfigure(0, weight=1)
    card.grid_rowconfigure(2, weight=1)
    return card, inner

def green_button(parent, text, cmd):
    return tk.Button(parent, text=text, command=cmd, bg="#2e7d32", fg="white",
                     activebackground="#1b5e20", activeforeground="white",
                     bd=0, padx=14, pady=6, cursor="hand2")

def grey_button(parent, text, cmd):
    return tk.Button(parent, text=text, command=cmd, bg="#757575", fg="white",
                     activebackground="#616161", activeforeground="white",
                     bd=0, padx=14, pady=6, cursor="hand2")

def upload_button(parent, text, cmd):
    return tk.Button(parent, text=text, command=cmd, bg="#0277bd", fg="white",
                     activebackground="#01579b", activeforeground="white",
                     bd=0, padx=14, pady=6, cursor="hand2")


# ==========================================================
# Clase principal de la aplicación
# ==========================================================

class App:
    def __init__(self, root):
        self.root = root
        self.root.title("Sistema de Rehabilitación de Rodilla")
        self.root.geometry("1280x720")
        self.root.resizable(False, False)

        # Crear barra de estado persistente
        self.status_bar = tk.Label(self.root, text="", bg="#222", fg="white", font=("Arial", 10))
        self.status_bar.pack(side="bottom", fill="x")

        self.current_user = None
        self.id_app = None

        self._ensure_status_bar()

        self._screen_login()

    # ===================== Adafruit IO =====================

    def _start_initial_sync(self, current_uid: str):
        """
        Sincroniza automáticamente todos los pacientes al iniciar la app.
        Usa hilos para no bloquear la interfaz.
        """

        def sync_thread():
            try:
                self._safe_status_update("🔄 Sincronizando datos con Adafruit IO...", "#c7a500")

                sync_users_with_cloud()

                users = list_users()
                pacientes = {uid: u for uid, u in users.items() if u.get("tipo") == "paciente"}

                for uid in pacientes.keys():
                    self._safe_status_update(f"⬆️ Subiendo datos pendientes de {uid}...", "#0277bd")
                    threaded_upload_user(uid)

                self._safe_status_update("✅ Sincronización en segundo plano iniciada", "#2e7d32")

            except Exception as e:
                print(f"[SYNC ERROR] {e}")
                self._safe_status_update("⚠️ Error durante sincronización", "#b71c1c")

        threading.Thread(target=sync_thread, daemon=True).start()

    # ==================== Barra de estado segura ====================

    def _ensure_status_bar(self):
        # Crea una sola barra de estado persistente (si no existe)
        if getattr(self, "status_bar", None) and self.status_bar.winfo_exists():
            return
        self.status_bar = tk.Label(self.root, text="", bg="#222222", fg="white", font=("Arial", 11))
        self.status_bar.place(relx=0, rely=1.0, anchor="sw", relwidth=1.0)

    def _safe_status_update(self, text, color=None):
        def _update():
            if not hasattr(self, "status_bar") or not self.status_bar.winfo_exists():
                return
            if color:
                self.status_bar.config(text=text, bg=color)
            else:
                self.status_bar.config(text=text)

        self.root.after(0, _update)

    # ==================== Utilidades ====================

    def _clear(self):
        """Elimina todos los widgets menos la barra de estado persistente."""
        for w in self.root.winfo_children():
            if w is getattr(self, "status_bar", None):
                continue  # mantener barra viva
            w.destroy()

    def _back_to_login(self):
        self._screen_login()


    # ==================== Pantalla de inicio de sesión ====================

    def _screen_login(self):
        self._clear()
        set_background(self.root, "imagenes/Costa_Rica.jpg")
        card, inner = make_card(self.root, "Sistema de rehabilitación de rodilla")

        # Configurar columnas para centrado
        inner.grid_columnconfigure(0, weight=1)
        inner.grid_columnconfigure(1, weight=1)

        # Campos centrados
        tk.Label(inner, text="Usuario (ID_app):", bg="#ffffff").grid(row=0, column=0, sticky="e", padx=6, pady=6)
        self.e_user = ttk.Entry(inner, width=26, justify="center")
        self.e_user.grid(row=0, column=1, padx=6, pady=6, sticky="ew")
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
